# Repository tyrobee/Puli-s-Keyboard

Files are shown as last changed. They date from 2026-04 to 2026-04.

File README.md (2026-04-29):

# Puli-s-Keyboard
I always wanted to get a keyboard but being a person who love making stuff on thier own instead of getting them so i started building the keyboard

i built the keyboard with 81 keys and a rotary encoder w a raspberrypi pico as the microcontroller and uses the open source  QMK firmware.It can also be called as a 78% Keyboard :))

## Schematics
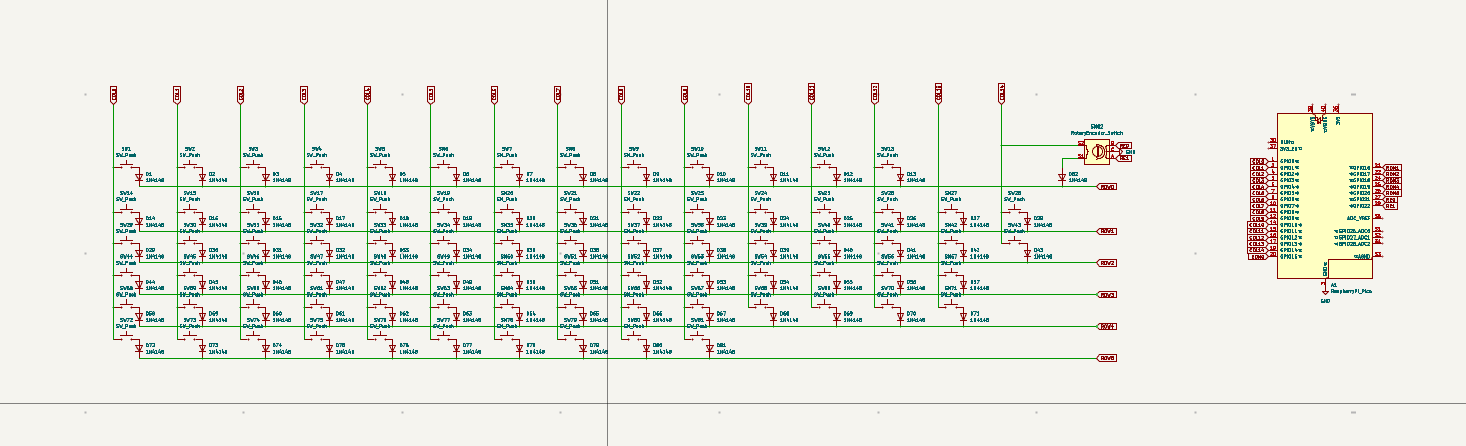
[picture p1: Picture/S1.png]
S1

## PCB
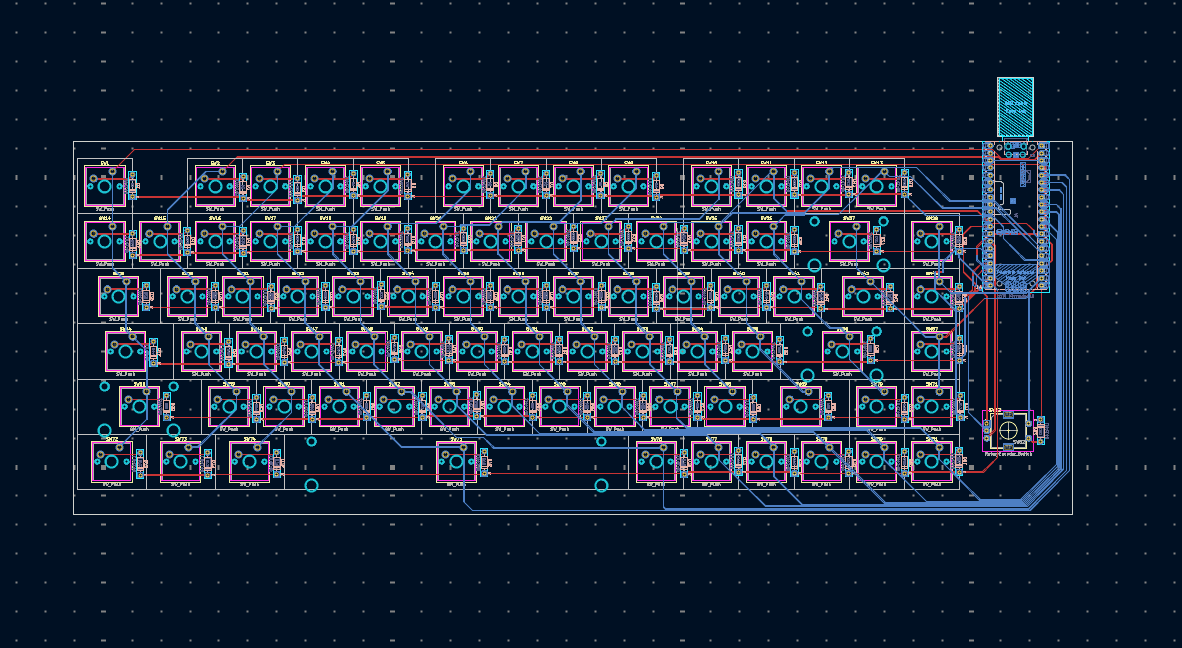
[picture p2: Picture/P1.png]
P1


## CAD
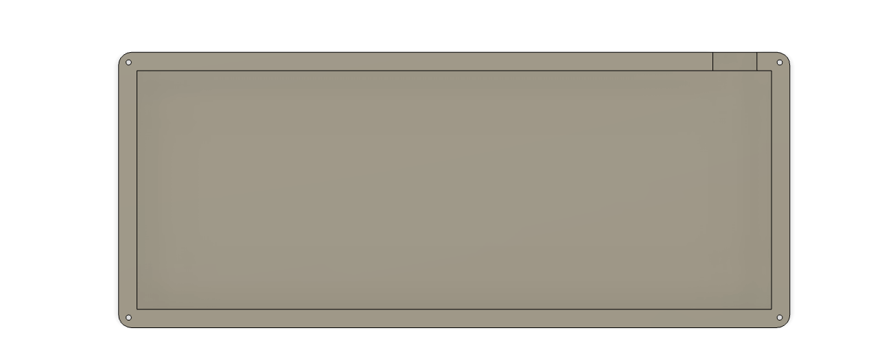
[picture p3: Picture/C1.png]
C1


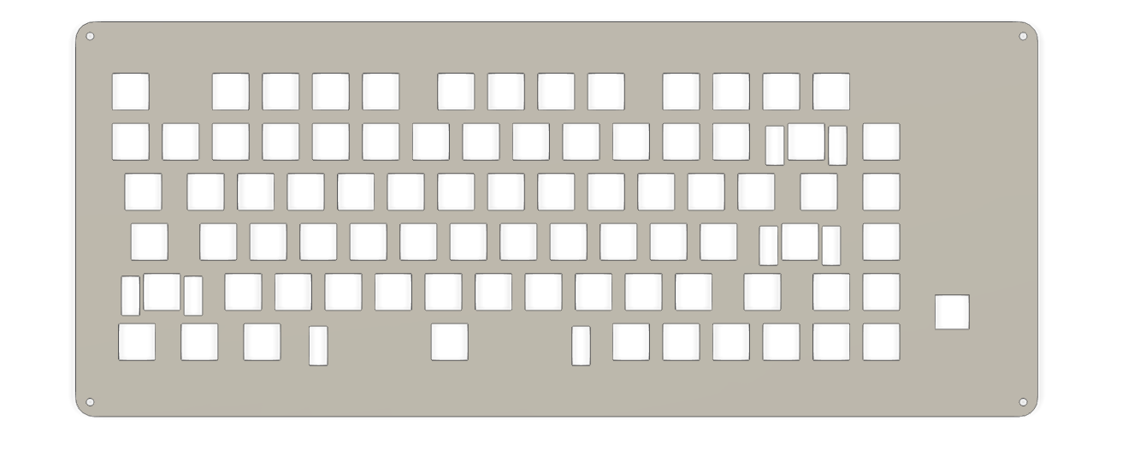
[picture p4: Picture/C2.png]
C2


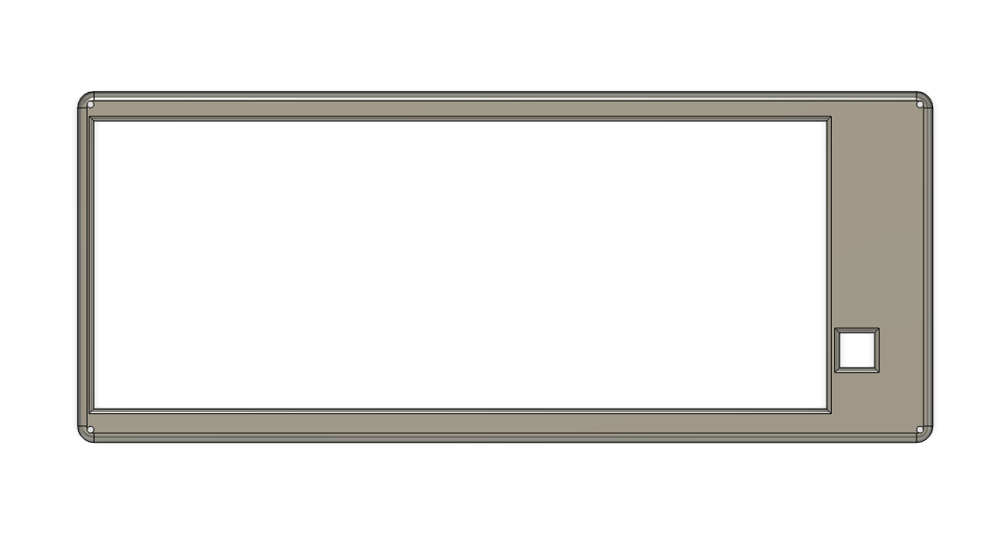
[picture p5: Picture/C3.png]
C3


## Assembly
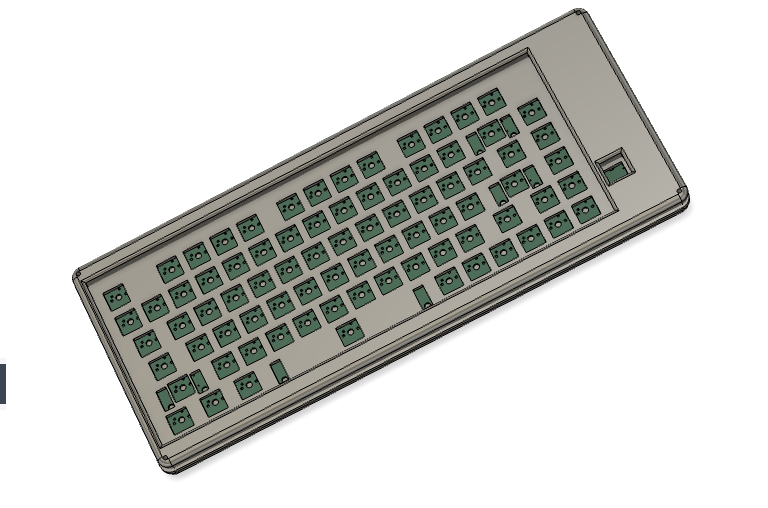
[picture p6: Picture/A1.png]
A1


## BOM

| Component | Purpose | Qty | Unit Cost ($) | Total ($) | Link | Distributor |
|---|---|-----|---|---|---|---|
| USB A Type to Micro USB B Cable | cable | 1 | 0.41| 0.41 | https://robocraze.com/products/usb-to-micro-usb-cable?variant=40192442007705 | Robu |
| female berg pins | connectors | 3 | 0.28 | 0.28 | https://robocraze.com/products/40x1-female-berg-strip?_pos=5&_sid=7dbcf9cbf&_ss=r | robocraze |
| Raspberry Pi Pico | microcontroller | 1 | 4.21 | 4.21 | https://robocraze.com/products/raspberry-pi-pico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 | Robocraze |
| 4x10 Enkeysphere Cherry Profile PBT Keycaps | keycaps | 1 | 21.17 | 21.17 | https://stackskb.com/store/hemisphere-keycaps/| StacksKB |
| Switches (Akko Creamy Cyan) | keys | 90 | 0.30 | 27.37 | https://stackskb.com/store/akko-creamy-cyan-switch-pack-of-45-pre-order/ | StacksKB |
|pcb | pcb | 1 |42.64 |42.64 | - | JLCPCB |

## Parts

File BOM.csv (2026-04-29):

Name | Purpose | Quantity | Total Cost (USD) | Link | Distributor
PCB | PCB | 1 | 42.64 |  | JLCPCB
USB A Type To Micro USB B Type 1M Cable | usb cable | 1 | 0.41 | https://robocraze.com/products/usb-to-micro-usb-cable?variant=40192442007705 | robocraze
female pins | connectors | 3 | 0.28 | https://robocraze.com/products/40x1-female-berg-strip?_pos=5&_sid=7dbcf9cbf&_ss=r | robocraze
raspberry pi pico | mcu | 1 | 4.21 | https://robocraze.com/products/raspberry-pi-pico?variant=40194204860569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 | Robocraze
Aflion Hemisphere Cherry Profile PBT Keycaps | keycaps | 1 | 21.07 | https://stackskb.com/store/hemisphere-keycaps/ | stacks
Switches | keys | 90 | 27.37 | https://stackskb.com/store/akko-creamy-cyan-switch-pack-of-45-pre-order/ | stacks

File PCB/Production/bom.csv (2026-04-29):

Designator | Footprint | Quantity | Value | LCSC Part #
A1 | RaspberryPi_Pico_Common_Unspecified | 1 | RaspberryPi_Pico
D1, D10, D11, D12, D13, D14, D15, D16, D17, D18, D19, D2, D20, D21, D22, D23, D24, D25, D26, D27, D28, D29, D3, D30, D31, D32, D33, D34, D35, D36, D37, D38, D39, D4, D40, D41, D42, D43, D44, D45, D46, D47, D48, D49, D5, D50, D51, D52, D53, D54, D55, D56, D57, D58, D59, D6, D60, D61, D62, D63, D64, D65, D66, D67, D68, D69, D7, D70, D71, D72, D73, D74, D75, D76, D77, D78, D79, D8, D80, D81, D82, D9 | D_DO-35_SOD27_P7.62mm_Horizontal | 82 | 1N4148
SW1, SW10, SW11, SW12, SW13, SW14, SW15, SW16, SW17, SW18, SW19, SW2, SW20, SW21, SW22, SW23, SW24, SW25, SW26, SW28, SW3, SW30, SW31, SW32, SW33, SW34, SW35, SW36, SW37, SW38, SW39, SW4, SW40, SW41, SW43, SW45, SW46, SW47, SW48, SW49, SW5, SW50, SW51, SW52, SW53, SW54, SW55, SW57, SW59, SW6, SW60, SW61, SW62, SW63, SW64, SW65, SW66, SW67, SW68, SW7, SW70, SW71, SW76, SW77, SW78, SW79, SW8, SW80, SW81, SW9 | SW_Cherry_MX_1.00u_PCB | 70 | SW_Push
SW27 | SW_Cherry_MX_2.00u_PCB | 1 | SW_Push
SW29, SW42 | SW_Cherry_MX_1.50u_PCB | 2 | SW_Push
SW44, SW69 | SW_Cherry_MX_1.75u_PCB | 2 | SW_Push
SW56, SW58 | SW_Cherry_MX_2.25u_PCB | 2 | SW_Push
SW72, SW73, SW74 | SW_Cherry_MX_1.25u_PCB | 3 | SW_Push
SW75 | SW_Cherry_MX_6.25u_PCB | 1 | SW_Push
SW82 | RotaryEncoder_Alps_EC11E-Switch_Vertical_H20mm | 1 | RotaryEncoder_Switch

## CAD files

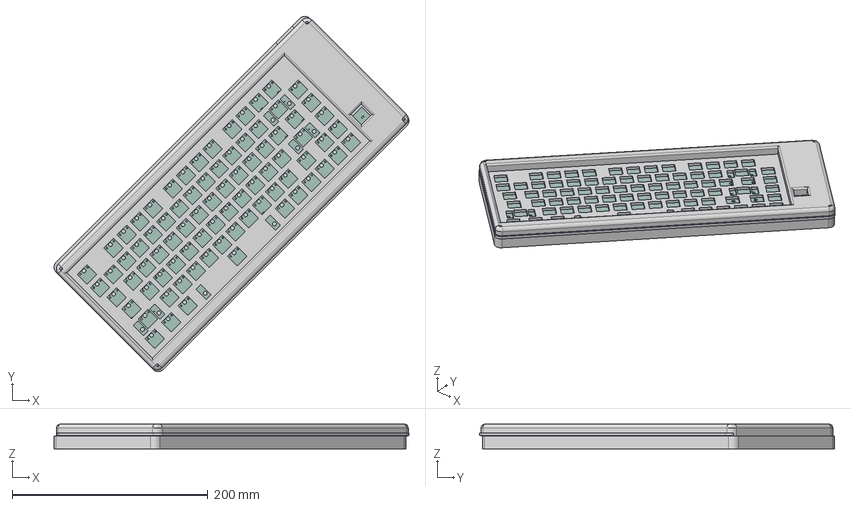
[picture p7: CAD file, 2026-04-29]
CAD/CAD source Files/Untitled.step
362.3 x 362.5 x 25.4 mm
D_DO-35_SOD27_P7.62mm_Horizontal x 82
RaspberryPi_Pico_Module_KiCad
Chaney_Board_PCB

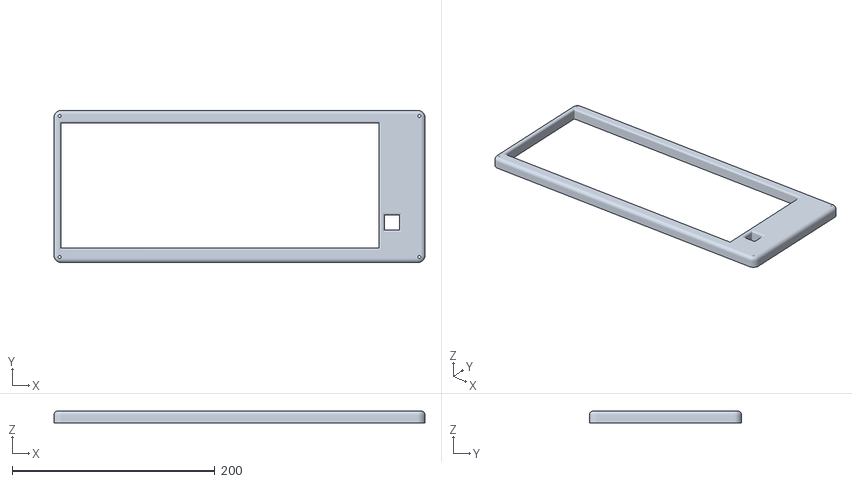
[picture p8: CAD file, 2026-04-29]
CAD/top.stl
366.2 x 150.2 x 12.0

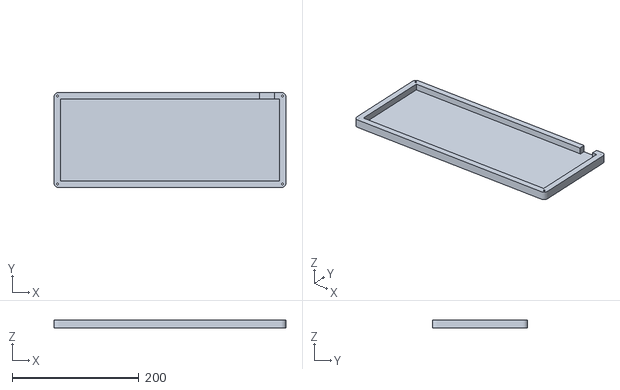
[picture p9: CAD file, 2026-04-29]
CAD/bottom.stl
366.2 x 150.2 x 13.0

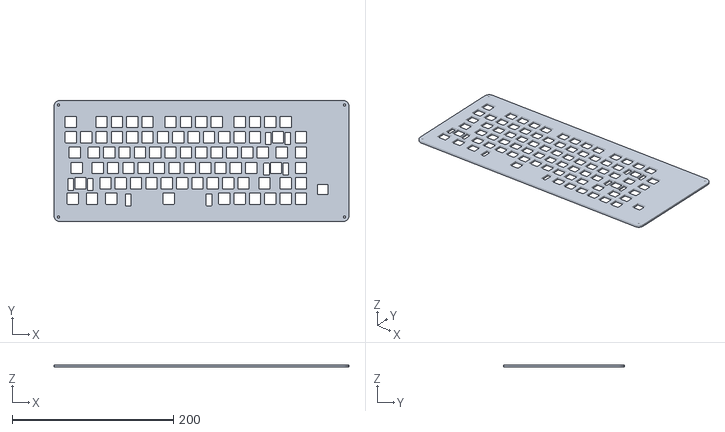
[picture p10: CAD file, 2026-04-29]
CAD/middle.stl
366.2 x 150.2 x 3.00

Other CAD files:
CAD/CAD source Files/bottom.f3d
CAD/CAD source Files/middle.f3d
CAD/CAD source Files/top.f3d

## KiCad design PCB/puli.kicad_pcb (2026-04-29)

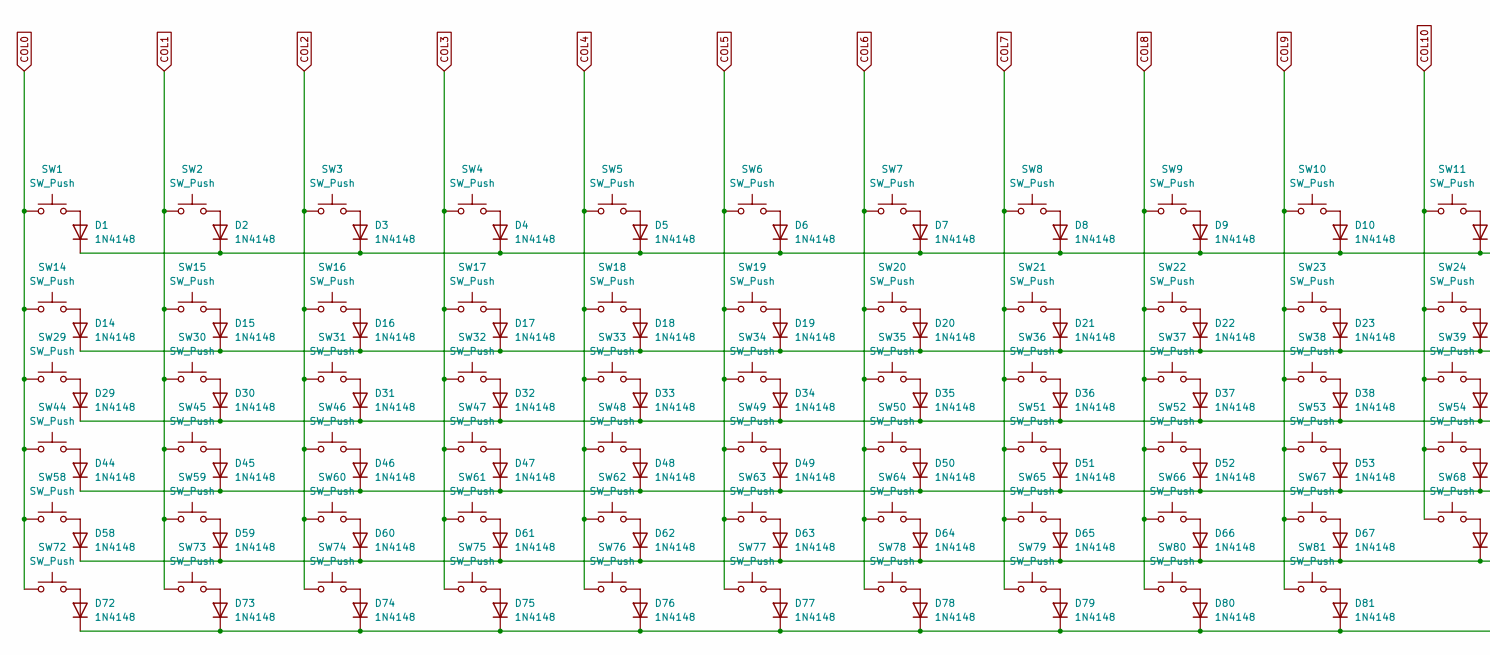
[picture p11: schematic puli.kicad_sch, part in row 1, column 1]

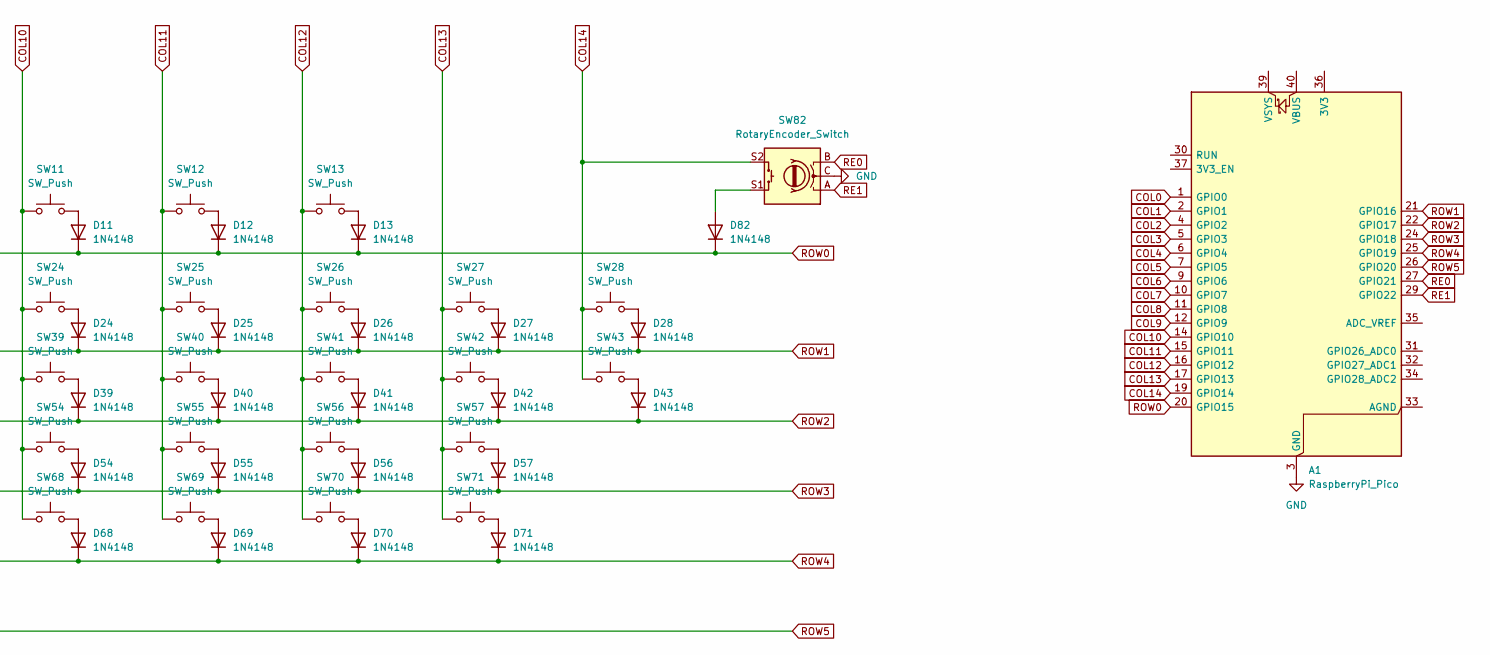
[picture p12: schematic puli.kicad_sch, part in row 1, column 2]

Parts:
A1: RaspberryPi_Pico; RaspberryPi_Pico_Common_Unspecified
D1, D2, D3, D4, D5, D6, D7, D8, D9, D10, D11, D12, D13, D14, D15, D16, D17, D18, D19, D20, D21, D22, D23, D24, D25, D26, D27, D28, D29, D30, D31, D32, D33, D34, D35, D36, D37, D38, D39, D40, D41, D42, D43, D44, D45, D46, D47, D48, D49, D50, D51, D52, D53, D54, D55, D56, D57, D58, D59, D60, D61, D62, D63, D64, D65, D66, D67, D68, D69, D70, D71, D72, D73, D74, D75, D76, D77, D78, D79, D80, D81, D82: 1N4148; D_DO-35_SOD27_P7.62mm_Horizontal
SW1, SW2, SW3, SW4, SW5, SW6, SW7, SW8, SW9, SW10, SW11, SW12, SW13, SW14, SW15, SW16, SW17, SW18, SW19, SW20, SW21, SW22, SW23, SW24, SW25, SW26, SW28, SW30, SW31, SW32, SW33, SW34, SW35, SW36, SW37, SW38, SW39, SW40, SW41, SW43, SW45, SW46, SW47, SW48, SW49, SW50, SW51, SW52, SW53, SW54, SW55, SW57, SW59, SW60, SW61, SW62, SW63, SW64, SW65, SW66, SW67, SW68, SW70, SW71, SW76, SW77, SW78, SW79, SW80, SW81: SW_Push; SW_Cherry_MX_1.00u_PCB
SW27: SW_Push; SW_Cherry_MX_2.00u_PCB
SW29, SW42: SW_Push; SW_Cherry_MX_1.50u_PCB
SW44, SW69: SW_Push; SW_Cherry_MX_1.75u_PCB
SW56, SW58: SW_Push; SW_Cherry_MX_2.25u_PCB
SW72, SW73, SW74: SW_Push; SW_Cherry_MX_1.25u_PCB
SW75: SW_Push; SW_Cherry_MX_6.25u_PCB
SW82: RotaryEncoder_Switch; RotaryEncoder_Alps_EC11E-Switch_Vertical_H20mm

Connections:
COL0: A1.1 (GPIO0), SW1.1, SW14.1, SW29.1, SW44.1, SW58.1, SW72.1
COL1: A1.2 (GPIO1), SW2.1, SW15.1, SW30.1, SW45.1, SW59.1, SW73.1
COL2: A1.4 (GPIO2), SW3.1, SW16.1, SW31.1, SW46.1, SW60.1, SW74.1
COL3: A1.5 (GPIO3), SW4.1, SW17.1, SW32.1, SW47.1, SW61.1, SW75.1
COL4: A1.6 (GPIO4), SW5.1, SW18.1, SW33.1, SW48.1, SW62.1, SW76.1
COL5: A1.7 (GPIO5), SW6.1, SW19.1, SW34.1, SW49.1, SW63.1, SW77.1
COL6: A1.9 (GPIO6), SW7.1, SW20.1, SW35.1, SW50.1, SW64.1, SW78.1
COL7: A1.10 (GPIO7), SW8.1, SW21.1, SW36.1, SW51.1, SW65.1, SW79.1
COL8: A1.11 (GPIO8), SW9.1, SW22.1, SW37.1, SW52.1, SW66.1, SW80.1
COL9: A1.12 (GPIO9), SW10.1, SW23.1, SW38.1, SW53.1, SW67.1, SW81.1
COL10: A1.14 (GPIO10), SW11.1, SW24.1, SW39.1, SW54.1, SW68.1
COL11: A1.15 (GPIO11), SW12.1, SW25.1, SW40.1, SW55.1, SW69.1
COL12: A1.16 (GPIO12), SW13.1, SW26.1, SW41.1, SW56.1, SW70.1
COL13: A1.17 (GPIO13), SW27.1, SW42.1, SW57.1, SW71.1
COL14: A1.19 (GPIO14), SW28.1, SW43.1, SW82.S2
GND: A1.3 (GND), A1.8 (GND), A1.13 (GND), A1.18 (GND), A1.23 (GND), A1.28 (GND), A1.38 (GND), SW82.C
unnamed: D1.2 (A), SW1.2
unnamed: D2.2 (A), SW2.2
unnamed: D3.2 (A), SW3.2
unnamed: D4.2 (A), SW4.2
unnamed: D5.2 (A), SW5.2
unnamed: D6.2 (A), SW6.2
unnamed: D7.2 (A), SW7.2
unnamed: D8.2 (A), SW8.2
unnamed: D9.2 (A), SW9.2
unnamed: D10.2 (A), SW10.2
unnamed: D11.2 (A), SW11.2
unnamed: D12.2 (A), SW12.2
unnamed: D13.2 (A), SW13.2
unnamed: D14.2 (A), SW14.2
unnamed: D15.2 (A), SW15.2
unnamed: D16.2 (A), SW16.2
unnamed: D17.2 (A), SW17.2
unnamed: D18.2 (A), SW18.2
unnamed: D19.2 (A), SW19.2
unnamed: D20.2 (A), SW20.2
unnamed: D21.2 (A), SW21.2
unnamed: D22.2 (A), SW22.2
unnamed: D23.2 (A), SW23.2
unnamed: D24.2 (A), SW24.2
unnamed: D25.2 (A), SW25.2
unnamed: D26.2 (A), SW26.2
unnamed: D27.2 (A), SW27.2
unnamed: D28.2 (A), SW28.2
unnamed: D29.2 (A), SW29.2
unnamed: D30.2 (A), SW30.2
unnamed: D31.2 (A), SW31.2
unnamed: D32.2 (A), SW32.2
unnamed: D33.2 (A), SW33.2
unnamed: D34.2 (A), SW34.2
unnamed: D35.2 (A), SW35.2
unnamed: D36.2 (A), SW36.2
unnamed: D37.2 (A), SW37.2
unnamed: D38.2 (A), SW38.2
unnamed: D39.2 (A), SW39.2
unnamed: D40.2 (A), SW40.2
unnamed: D41.2 (A), SW41.2
unnamed: D42.2 (A), SW42.2
unnamed: D43.2 (A), SW43.2
unnamed: D44.2 (A), SW44.2
unnamed: D45.2 (A), SW45.2
unnamed: D46.2 (A), SW46.2
unnamed: D47.2 (A), SW47.2
unnamed: D48.2 (A), SW48.2
unnamed: D49.2 (A), SW49.2
unnamed: D50.2 (A), SW50.2
unnamed: D51.2 (A), SW51.2
unnamed: D52.2 (A), SW52.2
unnamed: D53.2 (A), SW53.2
unnamed: D54.2 (A), SW54.2
unnamed: D55.2 (A), SW55.2
unnamed: D56.2 (A), SW56.2
unnamed: D57.2 (A), SW57.2
unnamed: D58.2 (A), SW58.2
unnamed: D59.2 (A), SW59.2
unnamed: D60.2 (A), SW60.2
unnamed: D61.2 (A), SW61.2
unnamed: D62.2 (A), SW62.2
unnamed: D63.2 (A), SW63.2
unnamed: D64.2 (A), SW64.2
unnamed: D65.2 (A), SW65.2
unnamed: D66.2 (A), SW66.2
unnamed: D67.2 (A), SW67.2
unnamed: D68.2 (A), SW68.2
unnamed: D69.2 (A), SW69.2
unnamed: D70.2 (A), SW70.2
unnamed: D71.2 (A), SW71.2
unnamed: D72.2 (A), SW72.2
unnamed: D73.2 (A), SW73.2
unnamed: D74.2 (A), SW74.2
unnamed: D75.2 (A), SW75.2
unnamed: D76.2 (A), SW76.2
unnamed: D77.2 (A), SW77.2
unnamed: D78.2 (A), SW78.2
unnamed: D79.2 (A), SW79.2
unnamed: D80.2 (A), SW80.2
unnamed: D81.2 (A), SW81.2
unnamed: D82.2 (A), SW82.S1
RE0: A1.27 (GPIO21), SW82.B
RE1: A1.29 (GPIO22), SW82.A
ROW0: A1.20 (GPIO15), D1.1 (K), D2.1 (K), D3.1 (K), D4.1 (K), D5.1 (K), D6.1 (K), D7.1 (K), D8.1 (K), D9.1 (K), D10.1 (K), D11.1 (K), D12.1 (K), D13.1 (K), D82.1 (K)
ROW1: A1.21 (GPIO16), D14.1 (K), D15.1 (K), D16.1 (K), D17.1 (K), D18.1 (K), D19.1 (K), D20.1 (K), D21.1 (K), D22.1 (K), D23.1 (K), D24.1 (K), D25.1 (K), D26.1 (K), D27.1 (K), D28.1 (K)
ROW2: A1.22 (GPIO17), D29.1 (K), D30.1 (K), D31.1 (K), D32.1 (K), D33.1 (K), D34.1 (K), D35.1 (K), D36.1 (K), D37.1 (K), D38.1 (K), D39.1 (K), D40.1 (K), D41.1 (K), D42.1 (K), D43.1 (K)
ROW3: A1.24 (GPIO18), D44.1 (K), D45.1 (K), D46.1 (K), D47.1 (K), D48.1 (K), D49.1 (K), D50.1 (K), D51.1 (K), D52.1 (K), D53.1 (K), D54.1 (K), D55.1 (K), D56.1 (K), D57.1 (K)
ROW4: A1.25 (GPIO19), D58.1 (K), D59.1 (K), D60.1 (K), D61.1 (K), D62.1 (K), D63.1 (K), D64.1 (K), D65.1 (K), D66.1 (K), D67.1 (K), D68.1 (K), D69.1 (K), D70.1 (K), D71.1 (K)
ROW5: A1.26 (GPIO20), D72.1 (K), D73.1 (K), D74.1 (K), D75.1 (K), D76.1 (K), D77.1 (K), D78.1 (K), D79.1 (K), D80.1 (K), D81.1 (K)

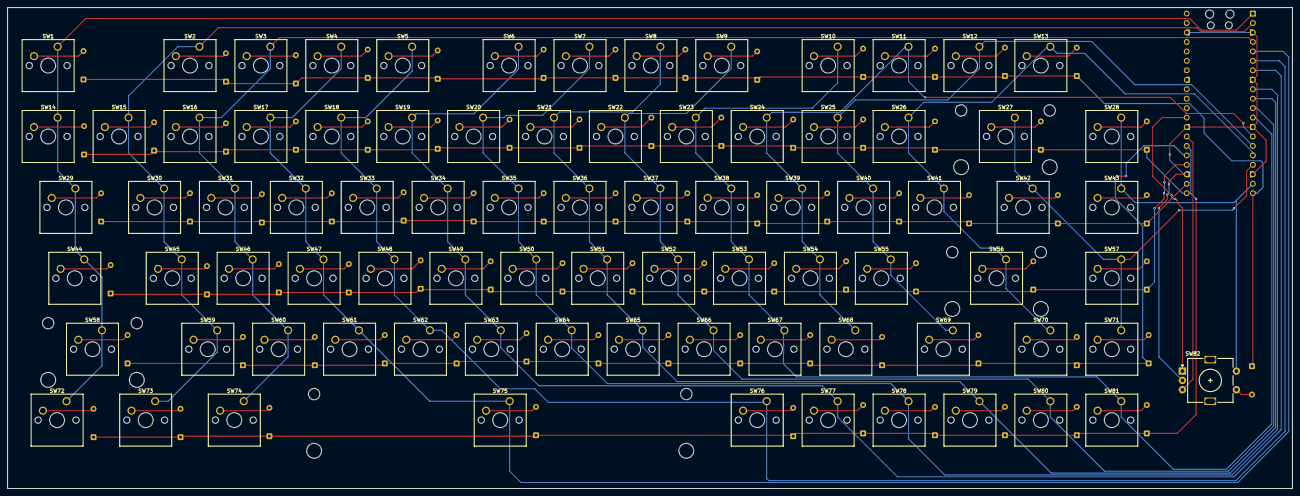
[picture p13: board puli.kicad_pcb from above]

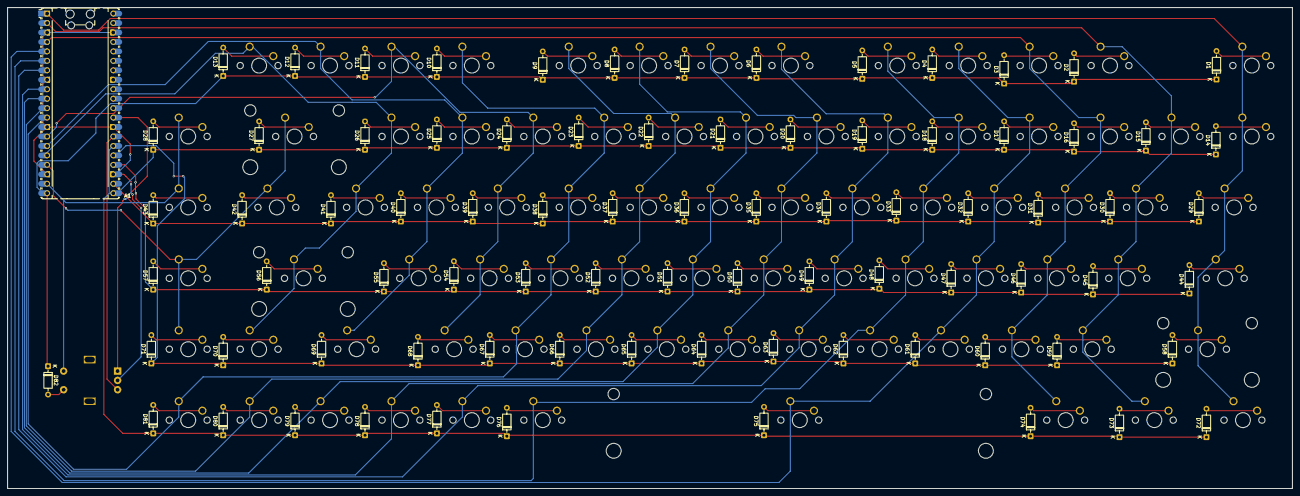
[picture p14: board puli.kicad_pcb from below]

Board: 2 copper layers, 345.2 x 129.2 mm, 165 parts (83 on the bottom side), 106 nets.

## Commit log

2026-04-29 Update README with additional images and sections
    Added images and sections for PCB, CAD, and Assembly.
2026-04-29 Add BOM section with component links to README
2026-04-29 Revise BOM with detailed component costs and links
    Updated the Bill of Materials (BOM) section with detailed component information, including purpose, unit cost, and total cost.
2026-04-29 Add PCB entry to the components list in README
